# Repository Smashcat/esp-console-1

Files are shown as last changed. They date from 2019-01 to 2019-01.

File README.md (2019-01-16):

# esp-console-1
Little hand-held ESP8266 based console with 240x320 LCD display, SDCard storage, 8 buttons and 2 sounders :) This includes an on-board programming circuit and USB serial port, so that it can be programmed easily using Arduino! Estimate around $12 in parts, including PCB, depending on PCB service and amount ordered - I used JLCPCB to buy 10.

I have recently received the PCBs back from JLCPCB for this design, and it works great!

Youtube video of older design here: https://www.youtube.com/watch?v=sWY_PZYmeA4

Photo of console board layout

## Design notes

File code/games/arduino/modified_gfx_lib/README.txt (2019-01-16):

This lib is used for the Tetris game. It should be added to your Arduino
library folder. The main modification is to allow direct access to the
sprite buffer for faster blitting, as gfx are stored in the correct format
to go straight to the display! There is no need to use this modified lib
unless you wish to compile the Tetris game.

Original library is here:
https://github.com/Bodmer/TFT_eSPI

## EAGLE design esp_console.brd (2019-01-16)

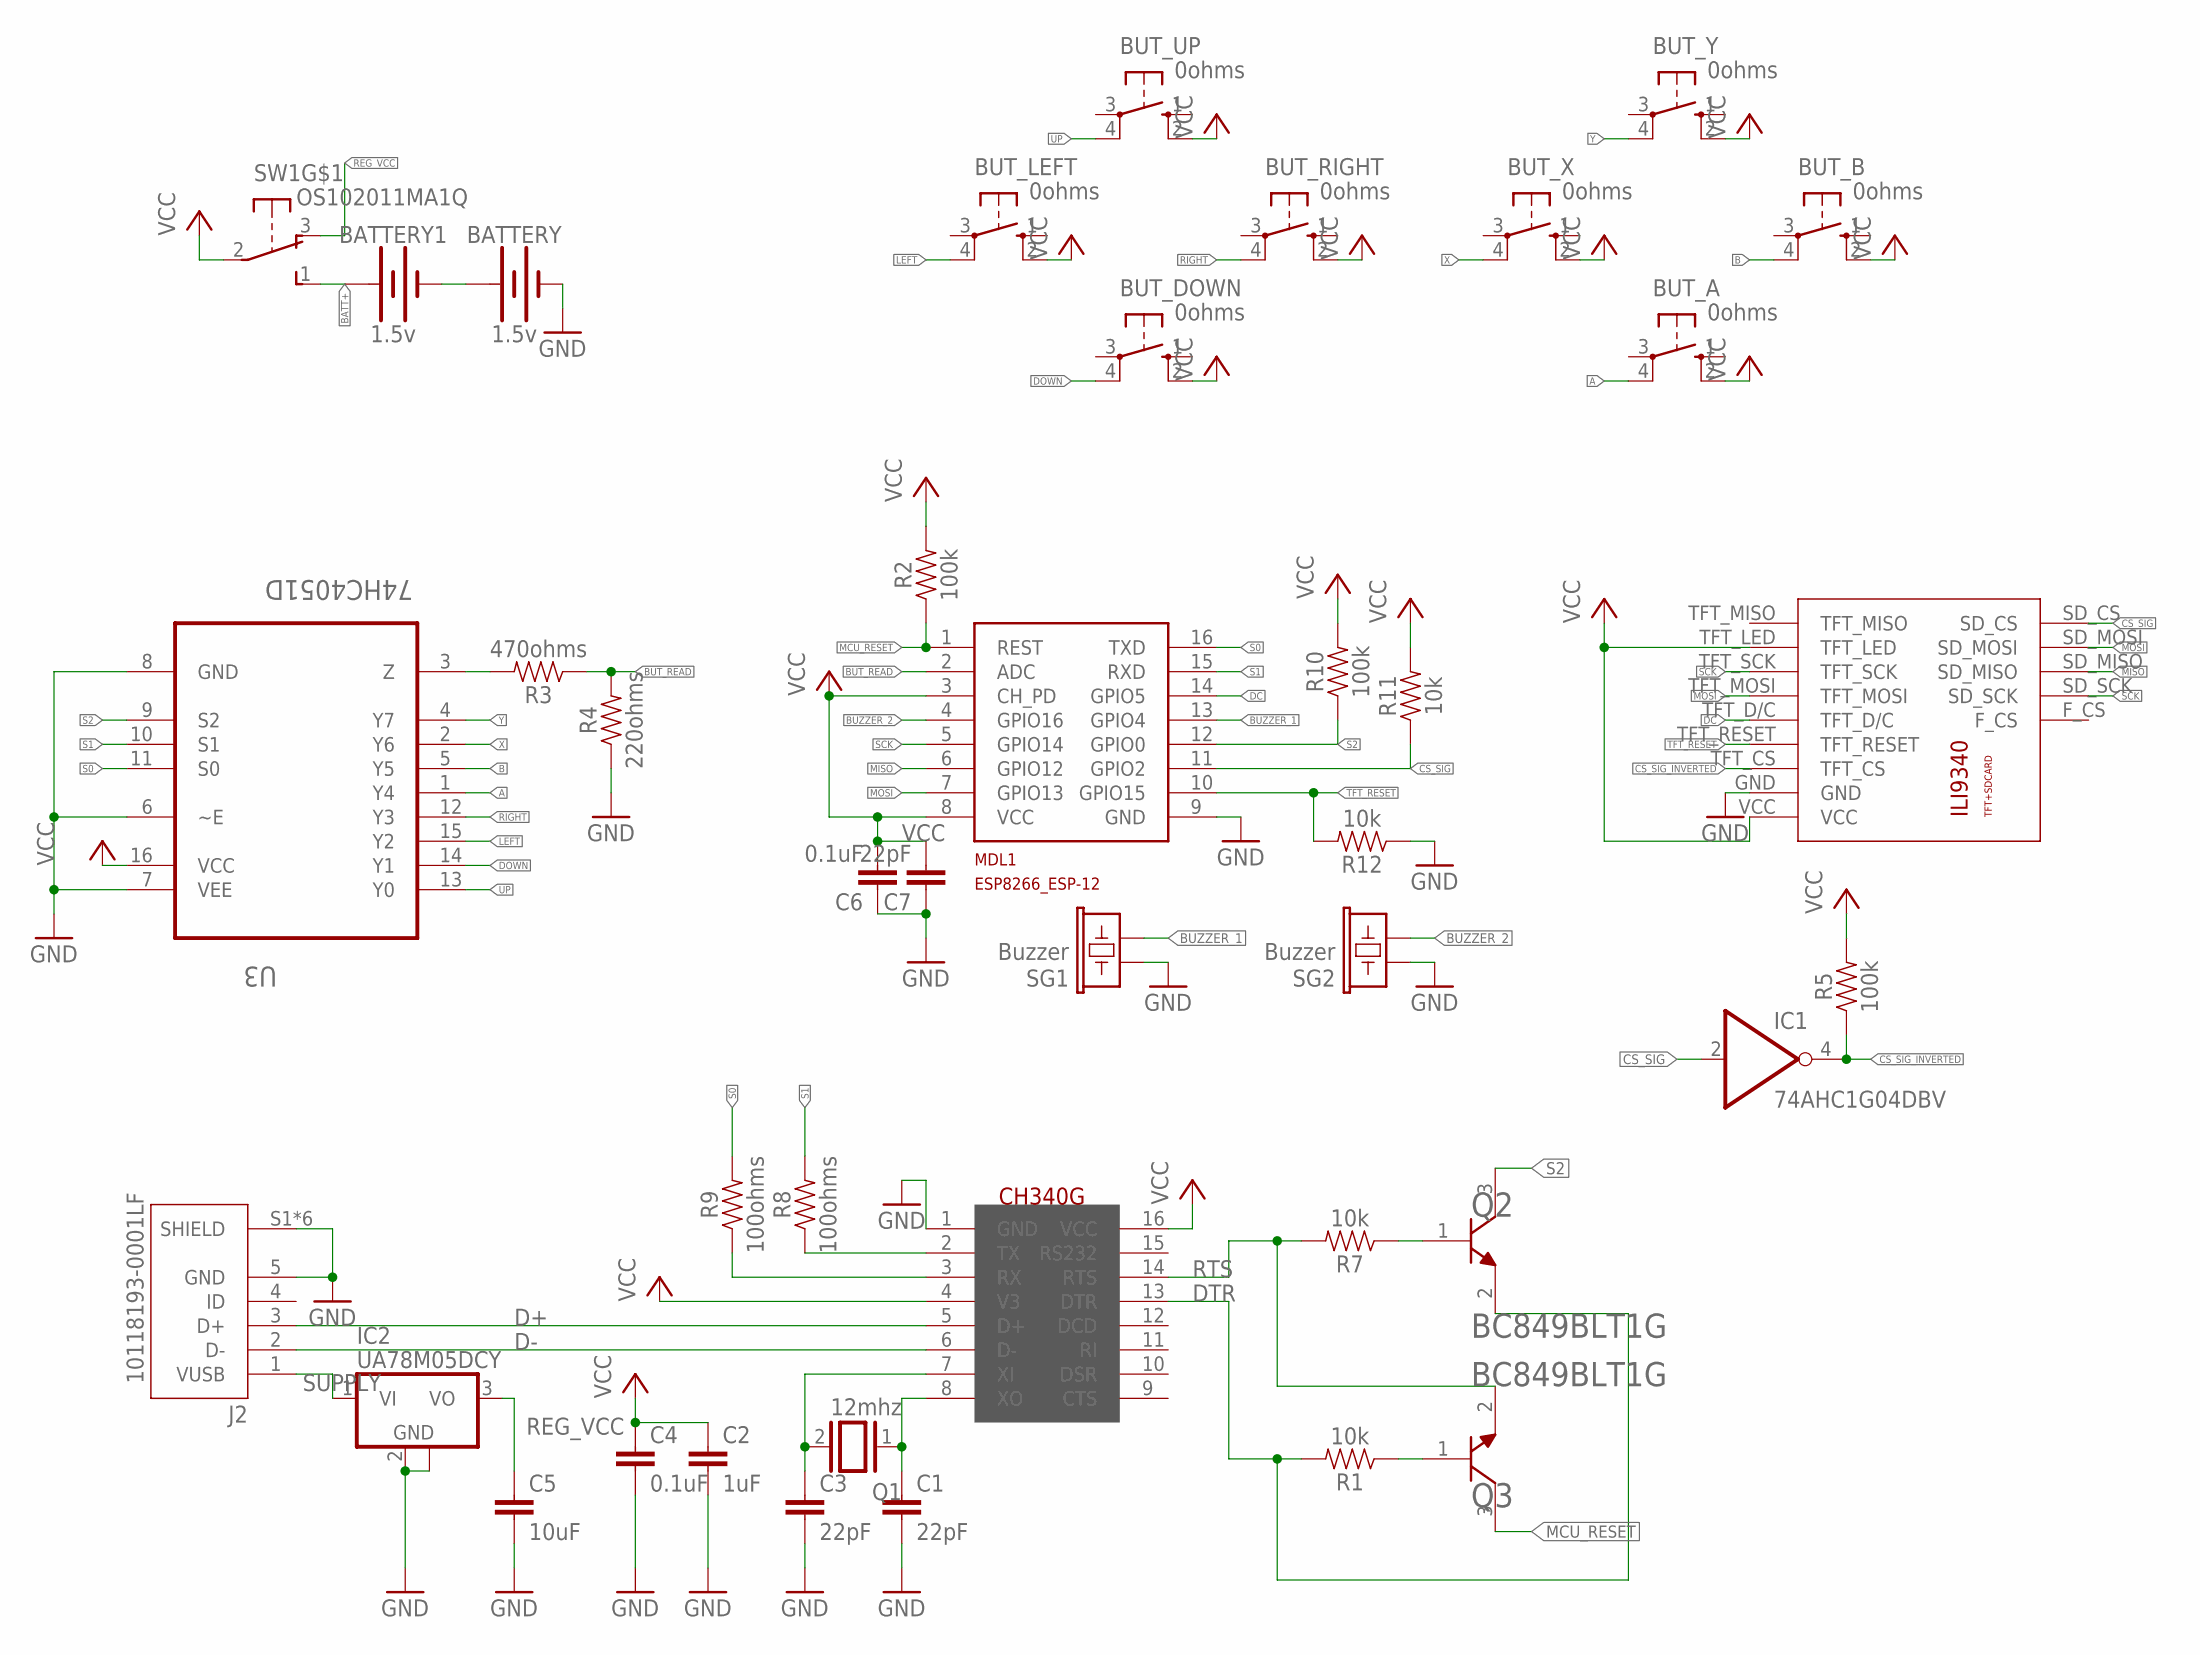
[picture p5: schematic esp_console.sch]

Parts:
BATTERY, BATTERY1: 1.5v; BATTERY-AA
BUT_A: 0ohms; B3F-10XX
BUT_B: 0ohms; B3F-10XX
BUT_DOWN: 0ohms; B3F-10XX
BUT_LEFT: 0ohms; B3F-10XX
BUT_RIGHT: 0ohms; B3F-10XX
BUT_UP: 0ohms; B3F-10XX
BUT_X: 0ohms; B3F-10XX
BUT_Y: 0ohms; B3F-10XX
C1, C3, C7: 22pF; C0603
C2: 1uF; C0603
C4, C6: 0.1uF; C0603
C5: 10uF; C0603
IC1: 74AHC1G04DBV; SOT23-5
IC2: UA78M05DCY; SOT223
J2: 10118193-0001LF; FCI_10118193-0001LF
MDL1: MCU; ESP8266-ESP12
Q1: 12mhz; QS
Q2, Q3: ON_SEMICONDUCTOR_BC849BLT1GON_SEMICONDUCTOR_BC849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; ON_SEMICONDUCTOR_BC849BLT1G_0
R1, R7, R11, R12: 10k; 0603
R2, R5, R10: 100k; 0603
R3: 470ohms; 0603
R4: 220ohms; 0603
R8, R9: 100ohms; 0603
SG1, SG2: Buzzer; BUZZER-CCV
SW1: OS102011MA1Q
U3: 74HC4051D; SOIC127P600X175-16N
U$1: CH340G; SOIC16
U$2: ILI9340-5PIN

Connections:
A: BUT_A.4 (P1), U3.1 (Y4)
B: BUT_B.4 (P1), U3.5 (Y5)
BATT+: BATTERY1.PWR@1 (+), SW1.1 (S)
BATT_LINK: BATTERY.PWR@1 (+), BATTERY1.GND@1 (-)
BUT_READ: MDL1.2 (ADC), R3.1, R4.2
BUT_READ_3V3: R3.2, U3.3 (Z)
BUZZER_1: MDL1.13 (GPIO4), SG1.- (2)
BUZZER_2: MDL1.4 (GPIO16), SG2.- (2)
CRYSTALIN: C3.1, Q1.2, U$1.7 (XI)
CRYSTALOUT: C1.1, Q1.1, U$1.8 (XO)
CS_SIG: IC1.2 (I), MDL1.11 (GPIO2), R11.1, U$2.SD_CS
CS_SIG_INVERTED: IC1.4 (O), R5.1, U$2.TFT_CS
D+: J2.3 (D+), U$1.5 (D+)
D-: J2.2 (D-), U$1.6 (D-)
DC: MDL1.14 (GPIO5), U$2.TFT_D/C
DOWN: BUT_DOWN.4 (P1), U3.14 (Y1)
DTR: Q2.2 (E), R1.2, U$1.13 (DTR)
GND: BATTERY.GND@1 (-), C1.2, C2.2, C3.2, C4.2, C5.2, C6.1, C7.1, IC1.3 (GND), IC2.2 (GND), IC2.4 (GND), J2.5 (GND), J2.S1 (SHIELD), J2.S2 (SHIELD), J2.S3 (SHIELD), J2.S4 (SHIELD), J2.S5 (SHIELD), J2.S6 (SHIELD), MDL1.9 (GND), R4.1, R12.1, SG1.+ (1), SG2.+ (1), U3.6 (~E), U3.7 (VEE), U3.8 (GND), U$1.1 (GND), U$2.GND
LEFT: BUT_LEFT.4 (P1), U3.15 (Y2)
MCU_RESET: MDL1.1 (REST), Q3.3 (C), R2.1
MISO: MDL1.6 (GPIO12), U$2.SD_MISO
MOSI: MDL1.7 (GPIO13), U$2.SD_MOSI, U$2.TFT_MOSI
unnamed: Q3.1 (B), R1.1
unnamed: Q2.1 (B), R7.1
REG_VCC: C5.1, IC2.3 (VO), SW1.3 (O)
RIGHT: BUT_RIGHT.4 (P1), U3.12 (Y3)
RTS: Q3.2 (E), R7.2, U$1.14 (RTS)
S0: MDL1.16 (TXD), R9.2, U3.11 (S0)
S1: MDL1.15 (RXD), R8.2, U3.10 (S1)
S2: MDL1.12 (GPIO0), Q2.3 (C), R10.1, U3.9 (S2)
SCK: MDL1.5 (GPIO14), U$2.SD_SCK, U$2.TFT_SCK
SUPPLY: IC2.1 (VI), J2.1 (VUSB)
TFT_RESET: MDL1.10 (GPIO15), R12.2, U$2.TFT_RESET
TXFROMMCU: R9.1, U$1.3 (RX)
TXFROMPROGRAMMER: R8.1, U$1.2 (TX)
UP: BUT_UP.4 (P1), U3.13 (Y0)
VCC: BUT_A.2 (S1), BUT_B.2 (S1), BUT_DOWN.2 (S1), BUT_LEFT.2 (S1), BUT_RIGHT.2 (S1), BUT_UP.2 (S1), BUT_X.2 (S1), BUT_Y.2 (S1), C2.1, C4.1, C6.2, C7.2, IC1.5 (VCC), MDL1.3 (CH_PD), MDL1.8 (VCC), R2.2, R5.2, R10.2, R11.2, SW1.2, U3.16 (VCC), U$1.4 (V3), U$1.16 (VCC), U$2.TFT_LED, U$2.VCC
X: BUT_X.4 (P1), U3.2 (Y6)
Y: BUT_Y.4 (P1), U3.4 (Y7)

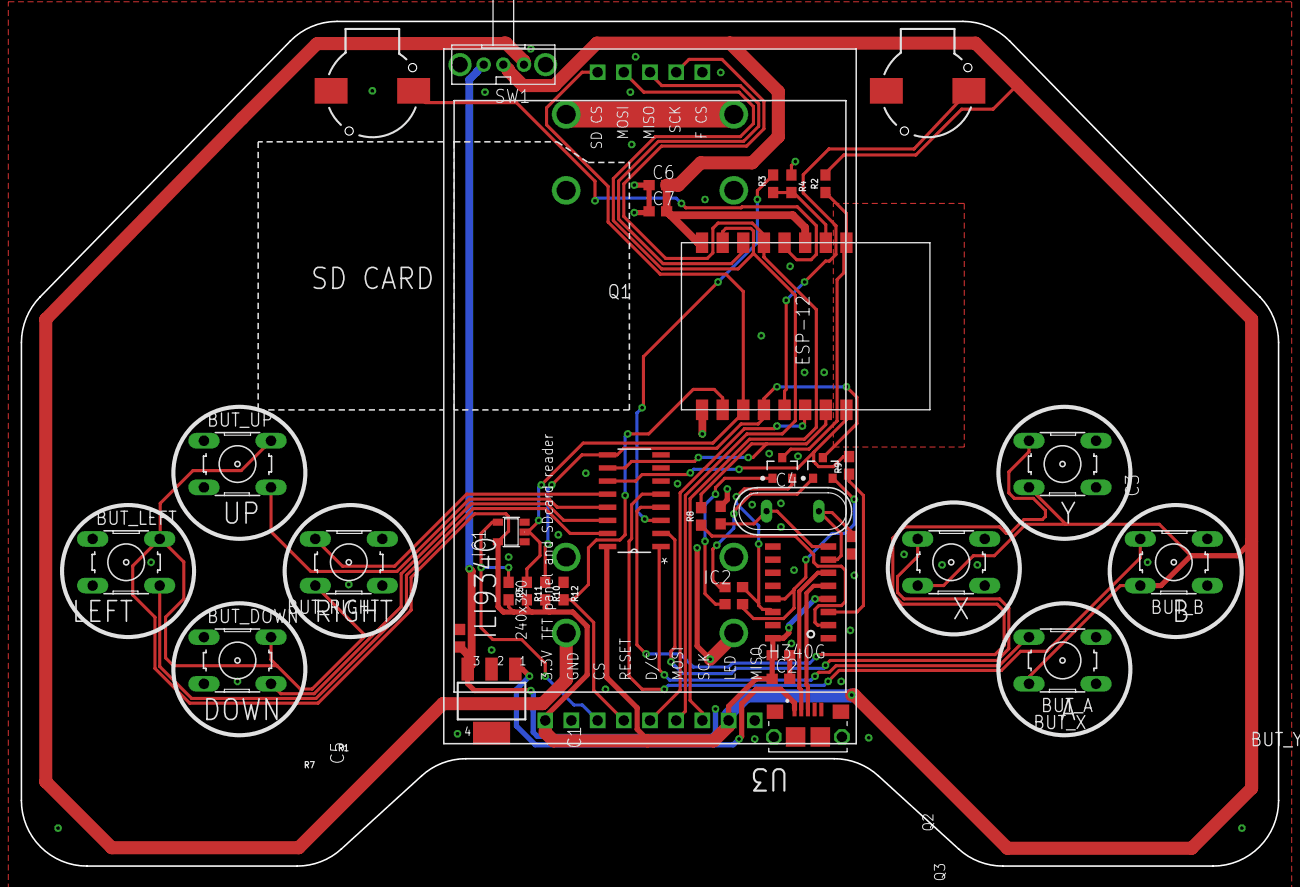
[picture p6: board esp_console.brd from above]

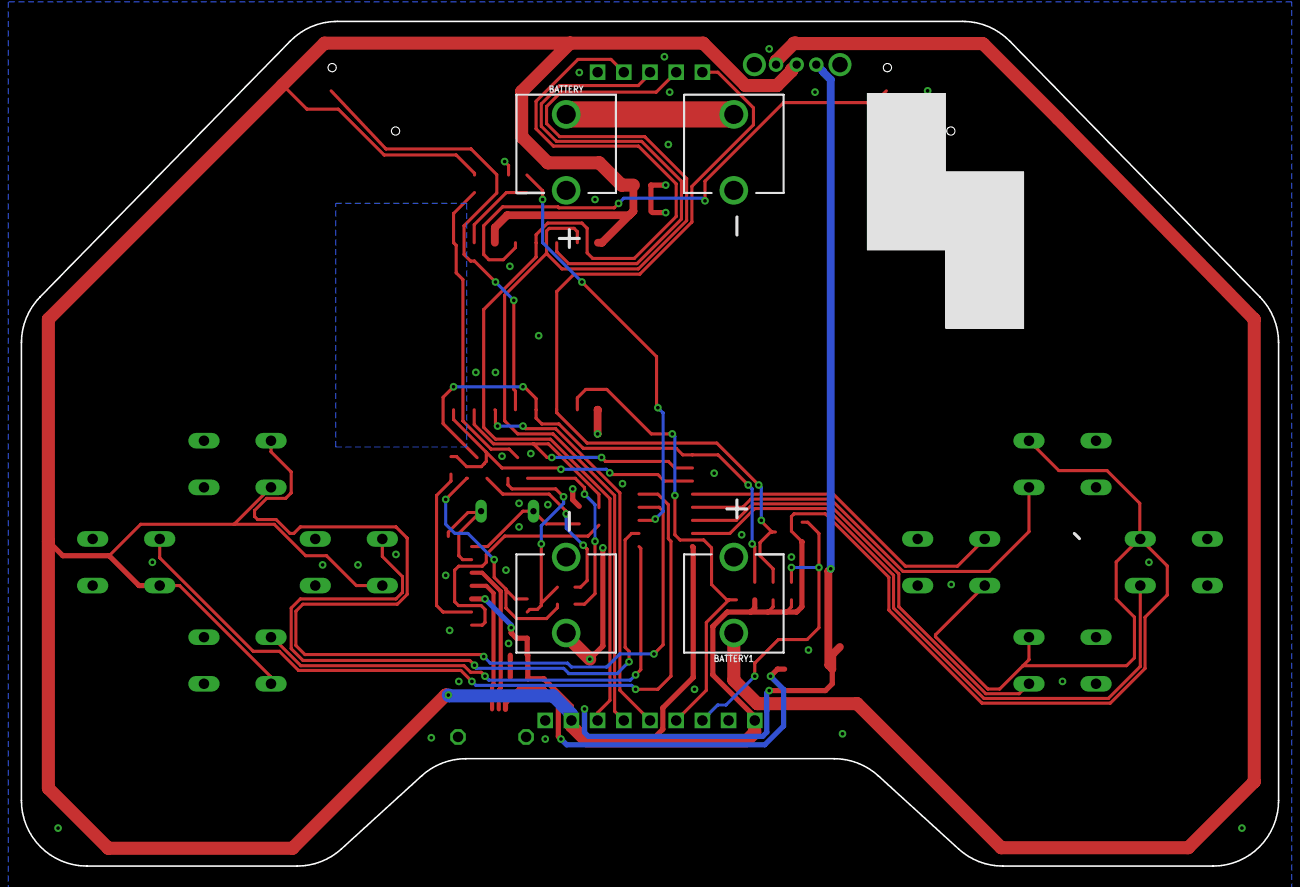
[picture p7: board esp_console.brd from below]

Board: 2 copper layers, 121.9 x 81.9 mm, 41 parts (2 on the bottom side), 39 nets.

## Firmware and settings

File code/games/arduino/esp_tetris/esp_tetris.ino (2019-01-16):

/**
 * NOTE - MAKE SURE RESET METHOD in Arduino IDE IS "NODEMCU"!!!!!!
 * Also, CPU speed can be 160mhz, but I have found on the modules
 * I have that the flash memory must be kept at 40mhz, and also the
 * flash mode must be DIO. The hardware supports the fastest upload
 * speed of 921600bps. I use "Generic ESP8266 module" as the target
 * device. Hopefully this should work for you!
 * 
 * The device can be powered by USB or 2 x AA batteries (last about 10 hours of use). 
 * The slide switch at the top will switch between the power source.
 */
 
#include "defs.h"
extern "C"
{
  #include "user_interface.h"
}

#include "pitches.h"
#include <EEPROM.h>
#if NEW_NETWORK
#include "WebSocketClient.h"
#include "ESP8266WiFi.h"

WebSocketClient webSocket(false);

#else
#include <WebSocketsClient.h>
#include <ESP8266WiFi.h>
WebSocketsClient webSocket;
#endif

#include "SPI.h"
#include "TFT_eSPI.h"
#include <Ticker.h>
#include "music.h"
#include "vars.h"
#include "gfx.h"
#include "headers.h"

TFT_eSPI tft = TFT_eSPI();
TFT_eSprite img = TFT_eSprite(&tft);
TFT_eSprite sprite1 = TFT_eSprite(&tft);
TFT_eSprite sprite2 = TFT_eSprite(&tft);
TFT_eSprite spriteTmp = TFT_eSprite(&tft);

#include "keyboard.h"
#include "menus.h"
#include "stars.h"
#if NEW_NETWORK
#include "networknew.h"
#else
#include "network.h"
#endif
#include "funcs.h"
#include "gameFuncs.h"
#include "screens.h"


void setup() {

  setSong(0);
  za = random(256);
  zb = random(256);
  zc = random(256);
  zx = random(256);
#if USE_SERIAL
  Serial.begin(115200);
  Serial.println("\n\nOK");
#else
  #if(DEVICE_VERSION==0 || DEVICE_VERSION==1)
  pinMode(BUT_RLEFT,INPUT_PULLUP);
  pinMode(BUT_RRIGHT,INPUT_PULLUP);
  #elif(DEVICE_VERSION==2)
  pinMode(BUT_0,INPUT);
  pinMode(BUT_1,INPUT_PULLUP);
  pinMode(BUT_2,INPUT_PULLUP);
  pinMode(OUT_0,INPUT);
  pinMode(OUT_1,INPUT);
  pinMode(CS_SELECT,OUTPUT);
  #elif(DEVICE_VERSION==3)
  pinMode(BUT_READ,INPUT);
  pinMode(S0,OUTPUT);
  pinMode(S1,OUTPUT);
  pinMode(S2,OUTPUT);
  pinMode(CS_SELECT,OUTPUT);
  #endif
#endif

#if(DEVICE_VERSION==1 || DEVICE_VERSION==3)
  setSpiTo(SCREEN);
  delay(25);
  pinMode(TFT_RST_PIN,OUTPUT);
  digitalWrite(TFT_RST_PIN, LOW);
  delay(25);
  digitalWrite(TFT_RST_PIN, HIGH);
  delay(100);
#endif

  makeColors();
  tft.init();
  tft.fillScreen(0);

  system_timer_reinit();
  os_timer_setfn(&timer, timerCallback, NULL);
  os_timer_arm(&timer, 10, true); // 50FPS

  //networkStatus=NETWORK_CONNECTING; //NETWORK_OFFLINE;
  networkStatus=NETWORK_OFFLINE;
  loadConfig();
  
#if USE_SERIAL
  Serial.print("Name = ");
  Serial.println(myName);
  Serial.print("SSID = ");
  Serial.println(wifiName);
  Serial.print("Pass = ");
  Serial.println(wifiPassword);
#endif
  setState(STATE_INTRO);
//  is2Player=true;
//  setState(STATE_PLAYING);
}

void loop() {
  checkWebSocket();
#if(!USE_SERIAL)
  checkButtons();
#endif
  if(state!=STATE_PLAYING){
    updateStars();
  }
  // Check connection status every second
  if(connectCheckTmr>=CONNECT_CHECK_INTERVAL){
    resetConnectCheckTmr();
    checkConnection();
  }
  if(state!=STATE_PLAYING){
    showNetworkStatus();
  }
  switch(state){
    
    case STATE_INTRO:
      showIntro();
      break;
      
    case STATE_TITLE_SCREEN:
      showTitleScreen();
      break;

    case STATE_PLAYING:
      showStatePlaying();
      break;

    case STATE_CHOOSE_OPPONENT:
      chooseOpponent();
      break;

    case STATE_HIGH_SCORES:
      showHighScores();
      break;
 
    case STATE_SETTINGS:
      showSettings();
      break;

    case STATE_HELP:
      showHelp();
      break;

    case STATE_SETUP_NAME:
      showSetupName();
      break;
    
    case STATE_SETUP_WIFI:
      showSetupWiFi();
      break;

    case STATE_SETUP_ABOUT:
      showSetupAbout();
      break;

    case STATE_CHALLENGED:
      showChallenged();
      break;
      
    default:
      break;
  }
  delay(1);
  yield();
}

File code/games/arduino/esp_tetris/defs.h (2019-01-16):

// 0 = dev edition (no on-board programming)
// 1 = xmas edition (no on-board programming)
// 2 = 6 button edition with on-board programming and SDcard access
// 3 = 8 button edition with on-board programming and SDcard access
#define DEVICE_VERSION       3

// True if using dev server for networking comms (addresses below)
#define DEV_SERVER        false

// True if serial port should output debugging data. Cannot be used in conjunction with A+B buttons
#define USE_SERIAL        false

// Leave following set to false - code is not finished!
#define NEW_NETWORK       false

// Number of starts in background of out-of-game screens
#define NSTARS            512


// There should be no need to alter anything below this line!

// Ping server once a minute
#define PING_INTERVAL     6000

#define TMP_STR_LEN       500

#if DEV_SERVER
#define GAME_SERVER_URL   "192.168.0.249"
#else
#define GAME_SERVER_URL   "your.server.url"
#endif

#define GAME_SERVER_PORT  1234
#define MAX_OPPONENTS     30
#define APP_SIG0          101
#define APP_SIG1          102

#if(DEVICE_VERSION==0)  // xmas version (6 buttons, no on-board programming)
#define BUT_UP       0
#define BUT_DOWN     2
#define BUT_LEFT     4
#define BUT_RIGHT   15
#define BUT_RLEFT    1
#define BUT_RRIGHT   3
#define TFT_RST_PIN 17
#define BUZZER      16
#define SCREEN      LOW
#define SDCARD      LOW
#elif(DEVICE_VERSION==1)  // 6 button programmable version
#define BUT_UP       0
#define BUT_DOWN     2
#define BUT_LEFT    12
#define BUT_RIGHT   15
#define BUT_RLEFT    1
#define BUT_RRIGHT   3
#define TFT_RST_PIN  4
#define BUZZER      16
#define SCREEN      LOW
#define SDCARD      LOW
#elif(DEVICE_VERSION==2)  // 6 button programmable version with SD card access and 2 buzzers
#define BUT_0       A0
#define BUT_1        3
#define BUT_2        1
#define OUT_0        0 
#define OUT_1        2
#define TFT_RST_PIN 17
#define BUZZER       4
#define BUZZER2     16
#define CS_SELECT   15
#define SCREEN      LOW
#define SDCARD      HIGH
#elif(DEVICE_VERSION==3)  // 8 button version with SD card access and 2 buzzers
#define S0           1
#define S1           3
#define S2           0
#define BUZZER       4
#define BUZZER2     16
#define TFT_RST_PIN 15
#define CS_SELECT    2
#define BUT_READ    A0
#define SCREEN      HIGH
#define SDCARD      LOW
#endif

#define DC         5
#define MISO      12
#define MOSI      13
#define SCLK      14

// program states
#define STATE_INTRO         0
#define STATE_TITLE_SCREEN  1
#define STATE_HIGH_SCORES   2
#define STATE_SETTINGS      3
#define STATE_HELP          4
#define STATE_SETUP_NAME    5
#define STATE_SETUP_WIFI    6
#define STATE_SETUP_ABOUT   7

// In game
#define STATE_CHALLENGED      70
#define STATE_PICK_PLAYER     80
#define STATE_GAME_START      90
#define STATE_PLAYING         100
#define STATE_CHOOSE_OPPONENT 110
#define STATE_GAME_END        120

#define RED_TO_YELLOW   0
#define GREEN_TO_BLUE   1
#define PURPLE_TO_WHITE 2
#define WHITE_TO_BLUE   3
#define RED_TO_BLUE     4
#define BLACK_TO_RED    5
#define BLACK_TO_BLACK  6

#define KS_IDLE         0
#define KS_OPENING      1
#define KS_EDITING      2
#define KS_CLOSING      3

// Actually 7 displayed shapes, but first is blank - makes some other logic easier :)
#define TOTAL_SHAPES      8
#define TOTAL_ROTATIONS   4
#define TOTAL_COORDINATES 4

#define KEYBOARD_ACTIVE 0
#define KEYBOARD_CLOSED 1
#define KEYBOARD_SAVED  2

#define GRID_X            16
#define GRID_Y            33
#define GRID_HEIGHT       23
#define GRID_WIDTH        10
#define FIRST_VISIBLE_ROW 3

// Speed of game at start (interval in 1/20 seconds between successive downward movements of player's block)
#define GAME_SPEED_START  30
// Maximum speed of game (as above)
#define GAME_SPEED_END    1
#define REPEAT_SPEED_RESET    20;
#define REPEAT_SPEED_REPEAT   2;


#define MY_NAME_IX      3
#define MY_NAME_LEN     17

#define WIFI_SSID_IX    20
#define WIFI_SSID_LEN   65

#define WIFI_PASS_IX    85
#define WIFI_PASS_LEN   65

#define SOUND_TYPE_IX   151

#define NETWORK_OFF         0
#define NETWORK_CONNECTING  1
#define NETWORK_CONNECTED   2
#define NETWORK_OFFLINE     3
#define NETWORK_UNDEFINED   4
#define WIFI_LOGO_DISPLAY_TIME  500
// 20 = 1 second
#define CONNECT_CHECK_INTERVAL  100
#define CURSOR_BLINK_SPEED      80

#define COLOR_GREY  0x421
#define COLOR_RED   0x78
#define COLOR_GREEN 0xE003
#define COLOR_BLUE  0x0F00

#define GAMESTATE_DROPPING  0
#define GAMESTATE_DROPPED   1
#define GAMESTATE_FAST_DROP 2
#define GAMESTATE_CLEARING  3
#define GAMESTATE_GAME_OVER 4
#define GAMESTATE_WE_WIN    5
#define GAMESTATE_WE_LOSE   6

#define RESPONSE_NONE       0
#define RESPONSE_ACCEPT     1
#define RESPONSE_REJECT     2
#define RESPONSE_BUSY       3

#define SOUND_NONE          0
#define SOUND_EFFECTS       1
#define SOUND_ALL           2

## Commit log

2018-12-29 Added schematics
    [esp_console.brd, esp_console.sch]
2019-01-03 Updated design to 8 buttons
    [esp_console.brd, esp_console.sch]
2019-01-03 New gerbers
2019-01-08 Added pullup to inverter, new gerbers
    [esp_console.brd, esp_console.sch]
2019-01-16 Added Tetris game and associated files
    [Configuring options.txt]
2019-01-16 Slight revision to wire routing, new gerbers
    [esp_console.brd, esp_console.sch]

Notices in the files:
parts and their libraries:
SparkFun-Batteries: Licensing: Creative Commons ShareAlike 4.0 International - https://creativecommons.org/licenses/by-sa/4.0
